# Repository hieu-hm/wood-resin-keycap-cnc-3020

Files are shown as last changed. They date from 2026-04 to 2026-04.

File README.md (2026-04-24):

# Wood Resin Keycap CNC 3020

Project for a 1u Cherry MX compatible keycap with a CNC-machined wood body and a resin stem/insert.

## Files

- `models/keycap_1u_cherry_mx_wood_body.stl` - wood body model for CAM.
- `models/keycap_1u_cherry_mx_resin_insert.stl` - square resin insert/pour block with underside Cherry MX female socket.
- `models/keycap_1u_cherry_mx_wood_resin_assembly.stl` - combined preview assembly.
- `models/keycap_1u_r1_square_recess.stl` - R1-style 1u keycap with only a square bottom recess.
- `models/keycap_1u_r1_sample_exact_square_recess.stl` - edited directly from the user's sample STL, with the underside cross removed and replaced by a square recess.
- `models/keycap_1u_hollow_bottom_no_stem.stl` - clean model drawn from scratch with a fully hollow underside and no stem.
- `drawings/keycap_1u_cherry_mx_layout.svg` - 2D dimension reference.
- `drawings/keycap_1u_r1_square_recess_layout.svg` - 2D reference for the square-recess variant.
- `drawings/keycap_1u_r1_sample_exact_square_recess_bottom.png` - bottom-view render of the sample-edited variant.
- `drawings/keycap_1u_r1_sample_exact_square_recess_side.png` - side-view render of the sample-edited variant.
- `drawings/keycap_1u_hollow_bottom_no_stem_bottom.png` - bottom-view render of the clean hollow model.
- `drawings/keycap_1u_hollow_bottom_no_stem_side.png` - side-view render of the clean hollow model.
- `cam/CNC_3020_PLUS_keycap_job_sheet.md` - machining notes for CNC 3020 Plus.
- `docs/README_keycap_1u_cherry_mx_wood_resin.md` - dimensions and manufacturing notes.
- `docs/README_keycap_1u_r1_square_recess.md` - dimensions for the square-recess variant.
- `docs/README_keycap_1u_r1_sample_exact_square_recess.md` - notes for the sample-edited exact variant.
- `docs/README_keycap_1u_hollow_bottom_no_stem.md` - notes for the clean hollow-bottom keycap.
- `scripts/make_keycap_mesh.py` - regenerates the STL/SVG/docs files.
- `scripts/make_keycap_r1_square_recess.py` - generates the R1-style square-recess variant.
- `scripts/edit_sample_r1_square_recess.py` - edits the provided sample STL and replaces the underside cross with a square recess.
- `scripts/make_keycap_hollow_bottom.py` - generates the clean hollow-bottom keycap from scratch.

## Nominal Dimensions

- Bottom: 18.2 x 18.2 mm.
- Top face: 12.8 x 12.8 mm.
- Height: 9.6 mm.
- Wall thickness: 1.25 mm.
- Top thickness: 1.65 mm.
- Resin pour pocket: 7.4 x 7.4 x 5.0 mm.
- Cherry MX socket: about 4.2 x 1.32 mm slots, centered, with about 5.0 mm resin depth available.

## Suggested Workflow

1. Open `models/keycap_1u_cherry_mx_wood_body.stl` in CAM.
2. Set units to millimeters.
3. Set origin at the keycap center, with Z zero on top of stock.
4. Machine the wood body and resin pocket.
5. Seal the wood, cast resin into the 7.4 x 7.4 x 5.0 mm square pocket or install the matching resin insert.
6. Machine/test the Cherry MX socket in resin.
7. Test fit on one switch before making a full set.

## CNC 3020 Plus Notes

Start from `cam/CNC_3020_PLUS_keycap_job_sheet.md`. Choose the postprocessor for your controller:

- GRBL/Candle: GRBL post, usually `.nc`.
- Mach3: Mach3 mill post, usually `.tap` or `.nc`.
- Offline controller: check the accepted extension before posting.

Run a CAM simulation and an air-cut before cutting the real blank.

## Regenerate Files

From the project root:

```powershell
python .\scripts\make_keycap_mesh.py
```

The script writes outputs back into `models/`, `drawings/`, and `docs/`.

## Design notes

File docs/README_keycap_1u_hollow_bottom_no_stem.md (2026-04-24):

# Keycap 1u hollow bottom, no stem

Clean model drawn from scratch for CNC/mesh preview.

Geometry:
- 1u outside bottom: 18.0 x 18.0 mm
- Overall height: about 9.6 mm
- Top reference: about 13.2 x 13.2 mm
- Bottom opening: about 14.8 x 14.8 mm
- Wall/rim thickness at bottom: about 1.6 mm
- Inner wall is near-vertical so the hollow roof matches the cavity cleanly.
- Underside is fully hollow and contains no Cherry MX stem, cross, post, bridge, or internal support.

Output:
- `keycap_1u_hollow_bottom_no_stem.stl`
- `keycap_1u_hollow_bottom_no_stem_bottom.png`
- `keycap_1u_hollow_bottom_no_stem_bottom_clean.png`
- `keycap_1u_hollow_bottom_no_stem_side.png`

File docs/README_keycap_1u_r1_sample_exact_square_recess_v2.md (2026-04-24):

# Keycap 1u R1 from sample - square recess bottom

This file is edited from the user's sample STL `1x1 R1.stl`.

Change made:
- removed the central Cherry-style cross/stem region on the underside
- replaced it with a square recessed pocket

Patch parameters used:
- square half-size: 2.8 mm
- square size: 5.60 mm
- recess depth from bottom: 3.90 mm

Output files:
- `keycap_1u_r1_sample_exact_square_recess_v2.stl`
- `keycap_1u_r1_sample_exact_square_recess_v2_bottom.png`
- `keycap_1u_r1_sample_exact_square_recess_v2_bottom_clean.png`
- `keycap_1u_r1_sample_exact_square_recess_v2_side.png`

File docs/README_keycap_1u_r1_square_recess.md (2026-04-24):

# Keycap 1u R1 style - square recessed bottom

Units: millimeters.

This model is a clean remake inspired by the reference `1x1 R1.stl`, but simplified underneath:
- no Cherry MX cross
- no resin stem geometry
- underside uses only a square recessed pocket

Generated files:
- `models/keycap_1u_r1_square_recess.stl`
- `drawings/keycap_1u_r1_square_recess_layout.svg`

Nominal dimensions:
- Bottom footprint: 18.0 x 18.0 mm
- Overall height: about 9.8 mm
- Top reference area: 13.0 x 13.0 mm
- Top reference offset: +0.8 mm in Y
- Bottom square recess: 7.4 x 7.4 x 5.0 mm deep

Notes:
- Model uses standard CAD orientation with Z up.
- Body is solid except for the square bottom recess.
- Top surface has an R1-style front/back slope plus a light dish.
- If you want the bottom recess larger, deeper, or offset, edit the values in `scripts/make_keycap_r1_square_recess.py`.

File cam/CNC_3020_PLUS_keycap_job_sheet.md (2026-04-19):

# CNC 3020 Plus job sheet - 1u Cherry MX wood + resin keycap

Units: millimeters.

Use these source files:
- Wood body CAM: `keycap_1u_cherry_mx_wood_body.stl`
- Resin insert CAM/test: `keycap_1u_cherry_mx_resin_insert.stl`
- Visual assembly only: `keycap_1u_cherry_mx_wood_resin_assembly.stl`
- 2D dimension reference: `keycap_1u_cherry_mx_layout.svg`

## Machine assumptions

- Machine: CNC 3020 Plus, 3-axis router.
- Work envelope is enough for one keycap.
- Controller can run standard G-code from CAM, commonly `.nc` or `.tap`.
- Verify whether your controller is GRBL/Candle, Mach3, or offline controller before posting G-code.

Do not run unverified G-code directly. First simulate in CAM, then air-cut above the stock.

## Suggested stock

For one keycap:
- Wood blank: 25 x 25 x 13 mm minimum.
- Safer blank: 30 x 30 x 15 mm.
- Final keycap body: about 18.2 x 18.2 x 9.6 mm.

Clamp the blank on a spoilboard. Leave at least 3 mm margin around the keycap for tabs or double-sided tape.

## Work coordinate setup

Recommended origin:
- X0/Y0: center of keycap.
- Z0: top of stock.

This matches the generated STL centerline and makes flipping/indexing easier.

## Tooling

For wood body:
- Roughing: 2.0 mm flat end mill.
- Finishing outer/top surface: 1.0 mm ball nose or 1.0 mm flat end mill.
- Inner cavity/pocket cleanup: 1.0 mm flat end mill.

For Cherry MX resin socket:
- Best: 0.8 mm to 1.0 mm flat end mill.
- Socket slot nominal is about 1.32 mm wide, so a 1.0 mm tool leaves room for finishing.

## Conservative starting feeds for small 3020 router

These are starting points only; reduce them if the spindle, frame, or bit chatters.

Wood with 1-2 mm carbide end mill:
- Spindle: 12000-18000 RPM.
- Feed: 250-600 mm/min.
- Plunge: 80-150 mm/min.
- Stepdown: 0.3-0.8 mm.
- Stepover roughing: 35-45%.
- Stepover finishing: 8-12%.

Resin with 0.8-1.0 mm end mill:
- Spindle: 10000-16000 RPM.
- Feed: 150-400 mm/min.
- Plunge: 50-100 mm/min.
- Stepdown: 0.2-0.4 mm.

## CAM operation order

### Wood body

1. Face stock lightly if needed.
2. 3D rough the outside body from `keycap_1u_cherry_mx_wood_body.stl`.
3. 3D finish the top surface.
4. Machine the underside cavity and resin pocket.
5. Machine the square resin pour pocket to about 7.4 x 7.4 x 5.0 mm.
6. Leave 0.15-0.30 mm clearance for the resin insert/pour because wood and resin dimensions move.
7. Cut the outer profile last, with tabs if not using strong double-sided tape.

### Resin stem/insert

Two practical options:

Option A - cast resin into the wood pocket:
- Seal the wood first.
- Cast resin into the 7.4 x 7.4 x 5.0 mm square pocket.
- After curing, re-zero on the underside center and machine the Cherry MX female socket.

Option B - machine/print separate insert:
- CAM from `keycap_1u_cherry_mx_resin_insert.stl`.
- Test fit in the wood pocket.
- Bond with epoxy or thin CA after checking switch fit.

## Cherry MX fit check

Before making a full set, cut only the resin socket test:
- Slot pair: about 4.2 x 1.32 mm, centered.
- Available resin depth: about 5.0 mm.
- If switch is too tight, increase slot width by 0.05 mm.
- If switch is loose, reduce slot width or use a tougher resin/epoxy mix.

## Postprocessor

Choose the postprocessor that matches your controller:
- GRBL/Candle: use a GRBL post and output `.nc`.
- Mach3: use a Mach3 mill post and output `.tap` or `.nc`.
- Offline 3020 controller: check whether it expects `.nc`, `.tap`, or `.txt`.

Minimum G-code features to confirm:
- Uses millimeters: `G21`.
- Absolute coordinates: `G90`.
- Safe retracts clear your clamps.
- Spindle command matches your controller: commonly `M3 S...`.
- Program end is accepted: commonly `M5` then `M30`.

## Safety checklist

- Simulate in CAM.
- Run an air-cut 5-10 mm above stock.
- Keep one hand near emergency stop.
- Confirm tool diameter in CAM matches the real bit.
- Confirm Z zero before every operation.
- Confirm the tool does not collide with clamps.
- Make one sacrificial test in cheap wood before using final wood/resin.

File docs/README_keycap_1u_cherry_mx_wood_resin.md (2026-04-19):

# Keycap 1u Cherry MX - wood body + resin stem insert

Units: millimeters.

Generated files:
- `keycap_1u_cherry_mx_wood_body.stl`: wooden outer keycap shell.
- `keycap_1u_cherry_mx_resin_insert.stl`: square resin insert/pour block with underside Cherry MX female socket.
- `keycap_1u_cherry_mx_wood_resin_assembly.stl`: combined preview assembly.
- `keycap_1u_cherry_mx_layout.svg`: 2D dimension reference for bottom/top/pocket/stem.

Nominal dimensions:
- 1u outside bottom: 18.2 x 18.2 mm.
- Top face: 12.8 x 12.8 mm.
- Height: 9.6 mm.
- Wall thickness: 1.25 mm.
- Top thickness: 1.65 mm.
- Resin pour pocket: 7.4 x 7.4 x 5.0 mm under the top.
- Cherry MX female socket: centered, about 4.2 x 1.32 mm each slot, depth about 5.0 mm available in resin.

Manufacturing notes:
- This is a practical starting model, not an official Cherry MX mechanical drawing.
- For CNC wood, leave 0.15-0.30 mm extra clearance around the resin insert depending on wood movement and resin shrinkage.
- Do a fit test before making a full set. Cherry-compatible switches and printers/CNC postprocessors vary.
- For resin casting, machine/print the wood body first, seal the wood, cast resin into the 7.4 x 7.4 x 5.0 mm square pocket, then finish-machine the Cherry MX socket in the resin if your casting process cannot hold that detail.
- For a production STEP file, remodel this parametric design in Fusion 360/SolidWorks/FreeCAD from the dimensions above and then toolpath from STEP.

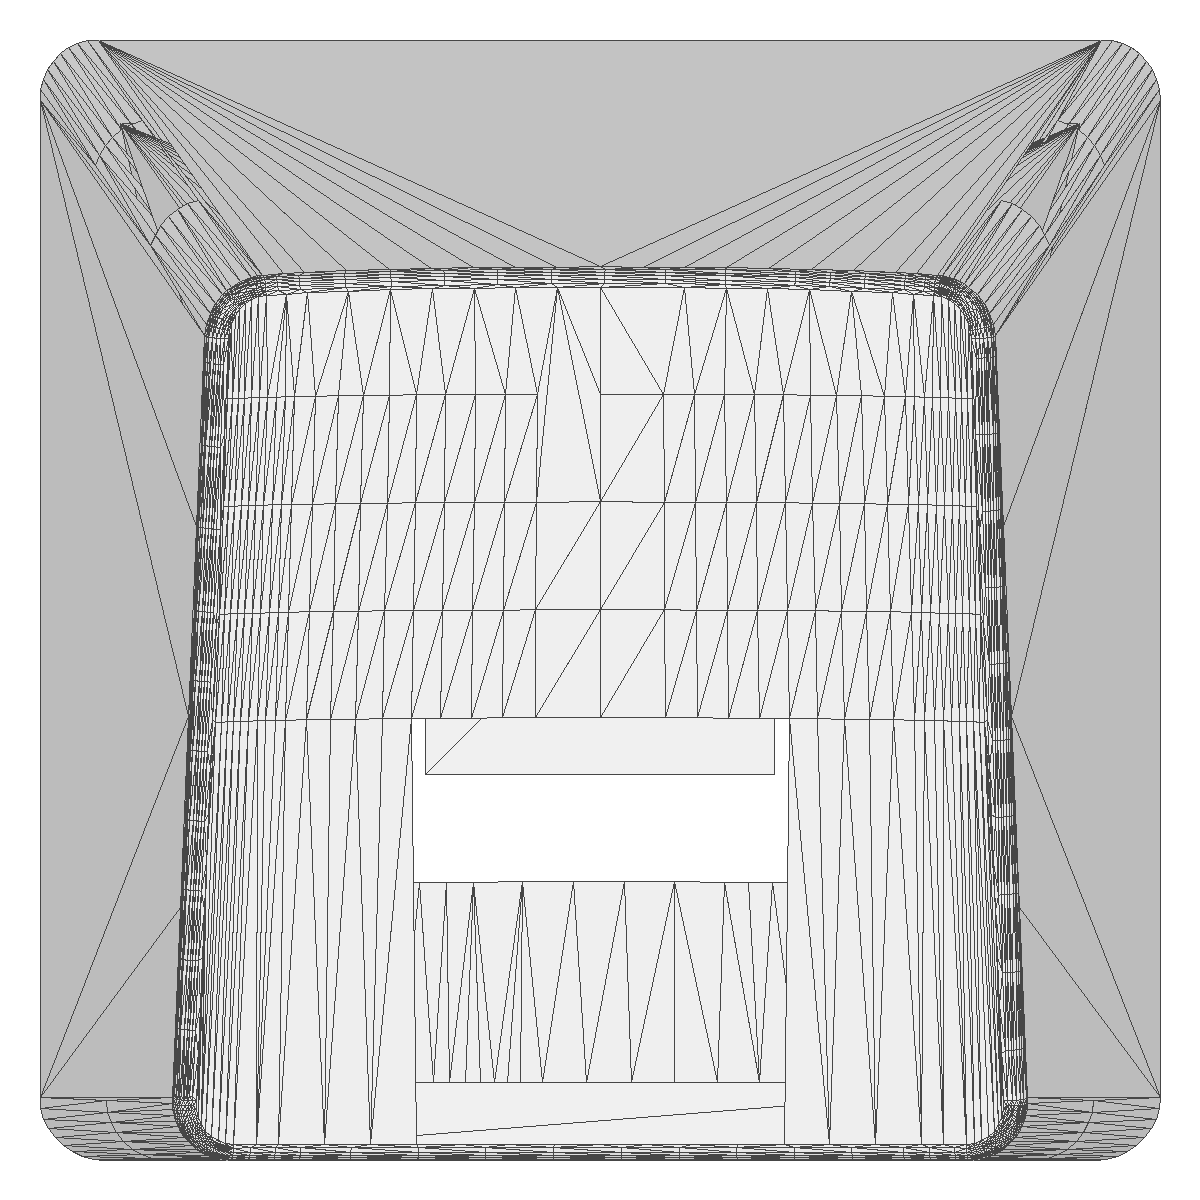
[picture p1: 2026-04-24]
drawings/keycap_1u_r1_sample_exact_square_recess_v2_bottom.png

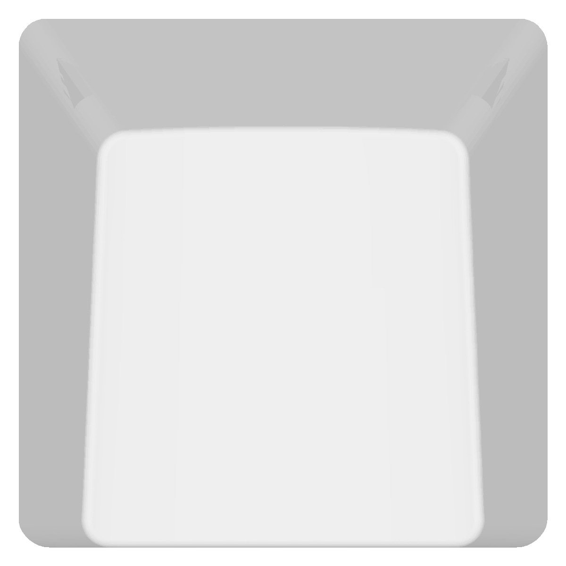
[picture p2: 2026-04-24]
drawings/keycap_1u_r1_sample_exact_square_recess_bottom_clean.png

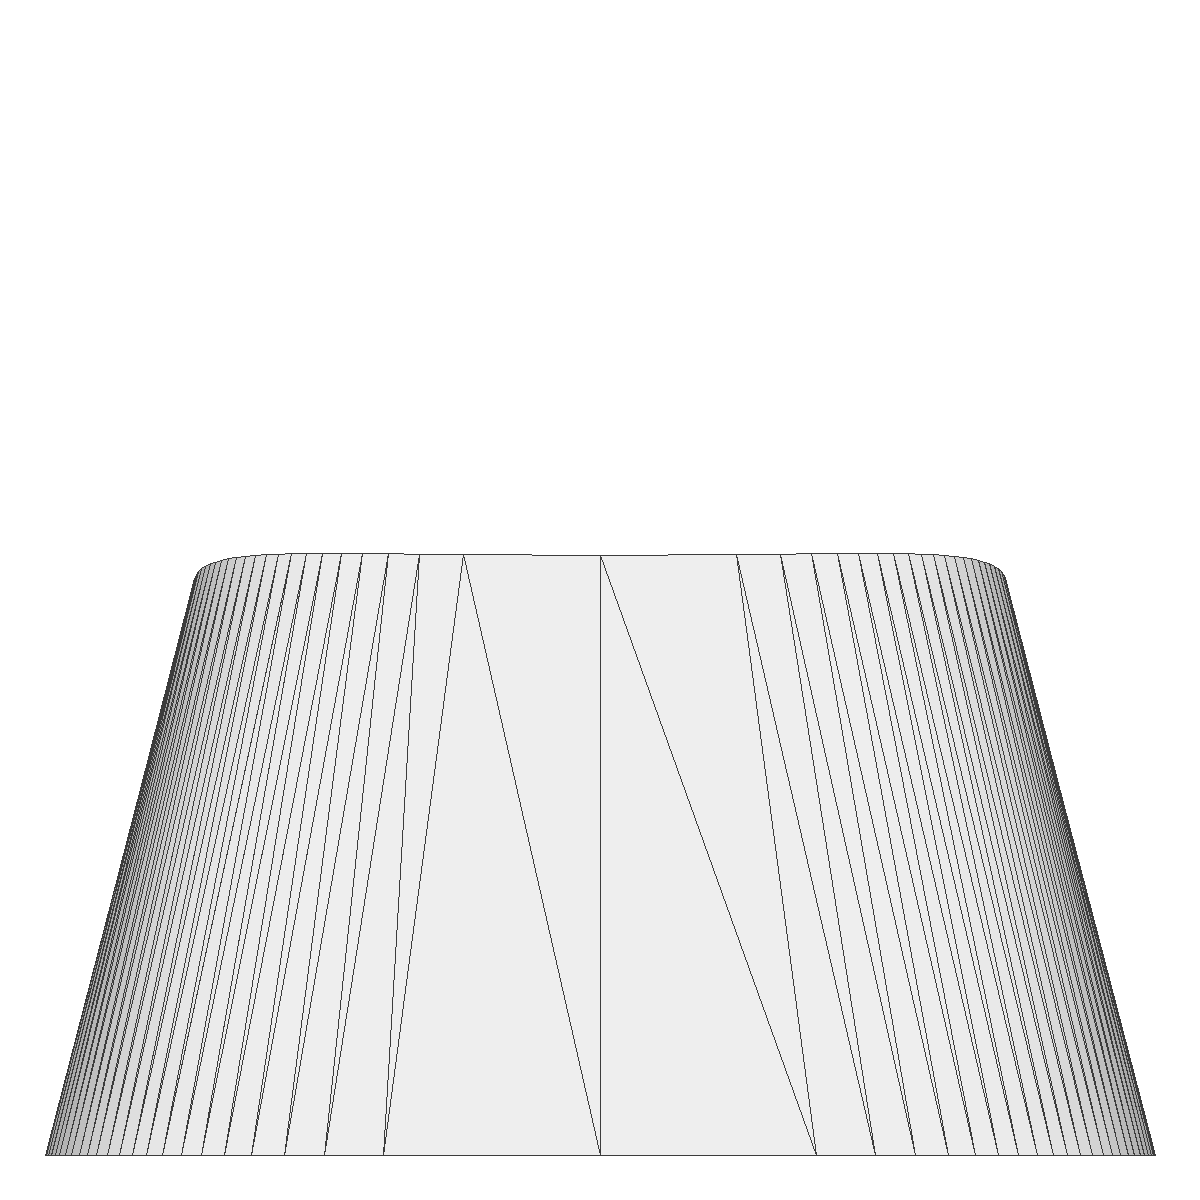
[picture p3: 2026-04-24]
drawings/keycap_1u_hollow_bottom_no_stem_flush_side.png

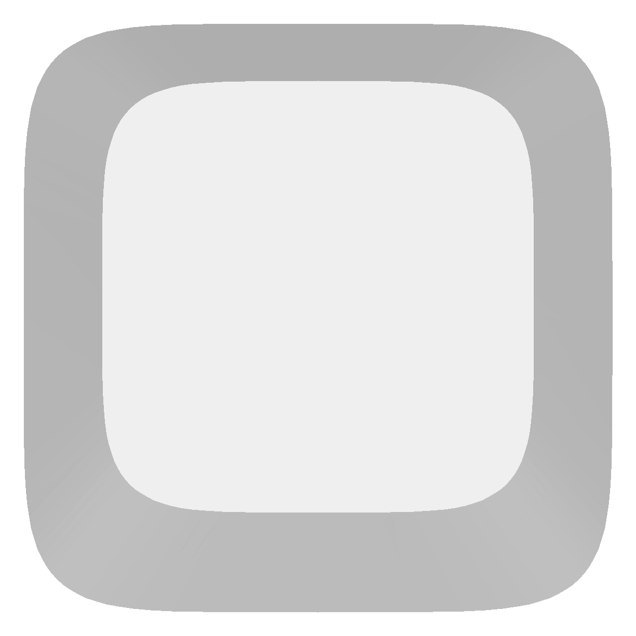
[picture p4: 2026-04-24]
drawings/keycap_1u_hollow_bottom_no_stem_bottom_clean.png

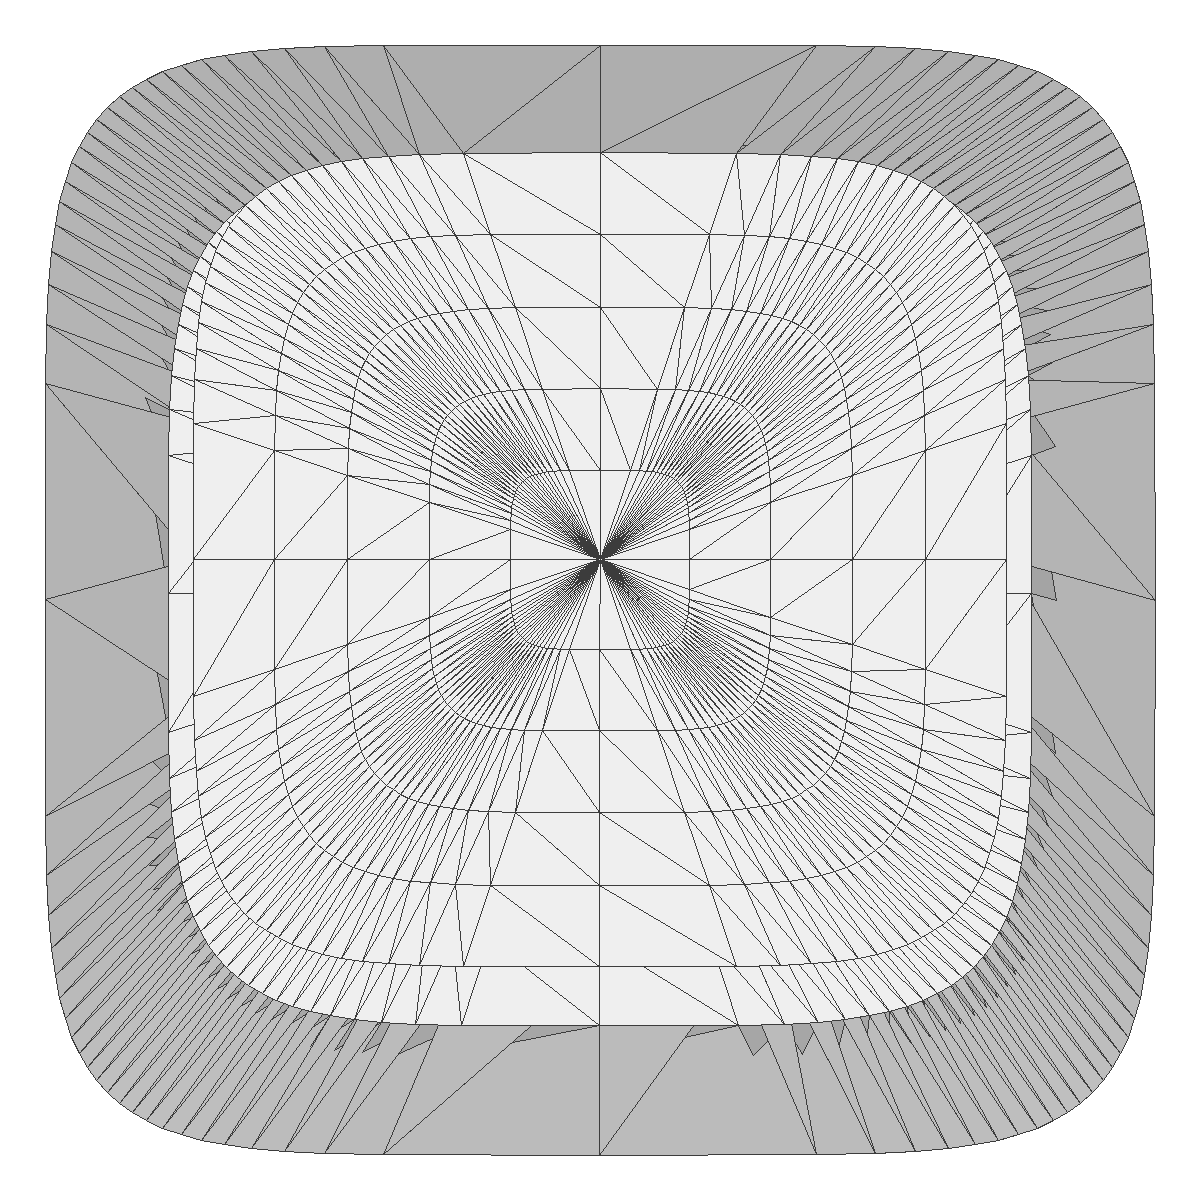
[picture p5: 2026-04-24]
drawings/keycap_1u_hollow_bottom_no_stem_bottom.png

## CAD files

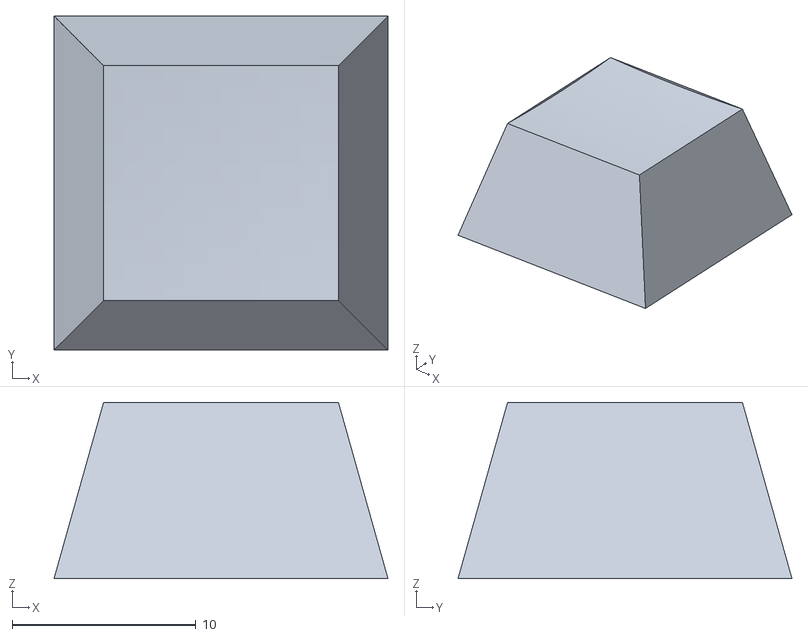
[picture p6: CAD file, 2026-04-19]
models/keycap_1u_cherry_mx_wood_resin_assembly.stl
18.2 x 18.2 x 9.60

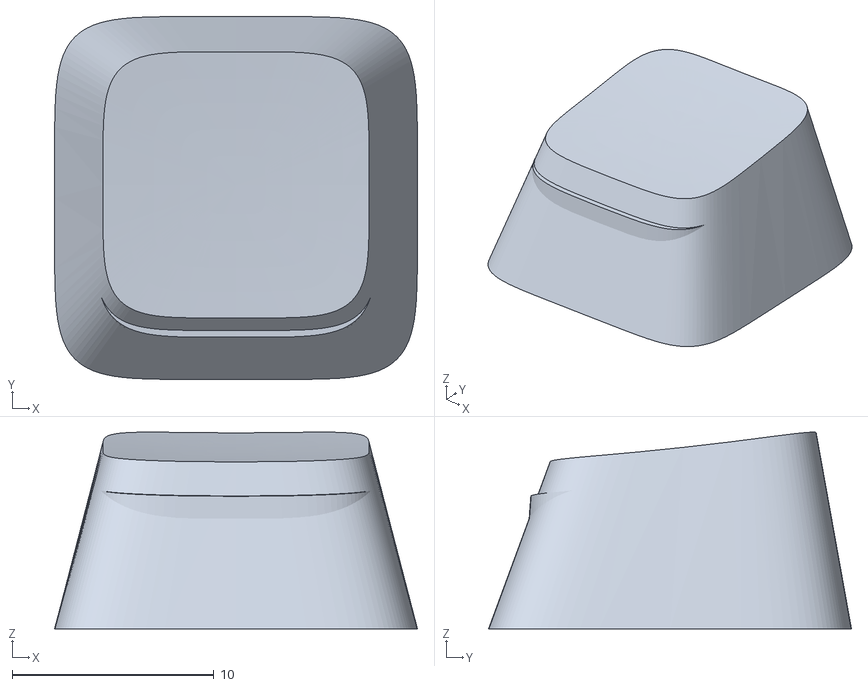
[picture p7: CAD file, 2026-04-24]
models/keycap_1u_hollow_bottom_no_stem_flush.stl
18.0 x 18.0 x 9.76

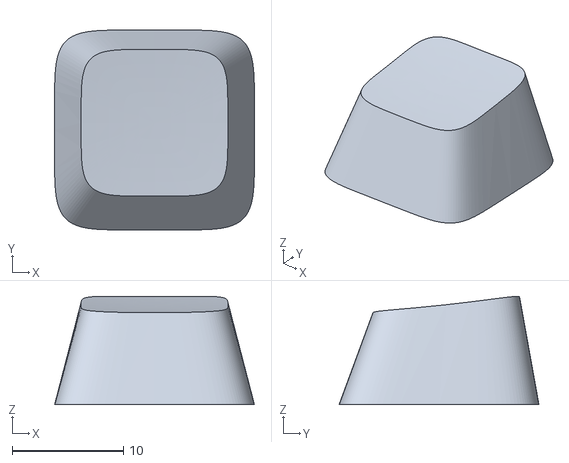
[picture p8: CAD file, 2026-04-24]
models/keycap_1u_hollow_bottom_no_stem.stl
18.0 x 18.0 x 9.76

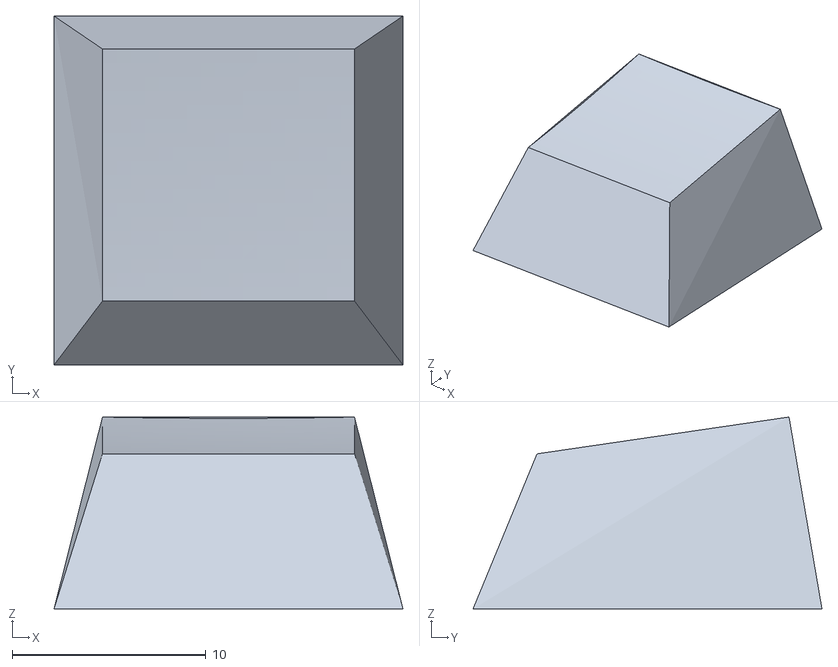
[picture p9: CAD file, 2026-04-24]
models/keycap_1u_r1_square_recess.stl
18.0 x 18.0 x 9.90

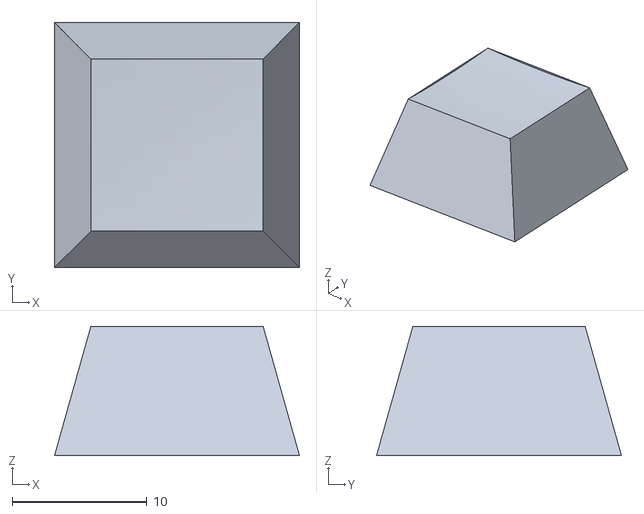
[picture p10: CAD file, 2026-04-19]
models/keycap_1u_cherry_mx_wood_body.stl
18.2 x 18.2 x 9.60

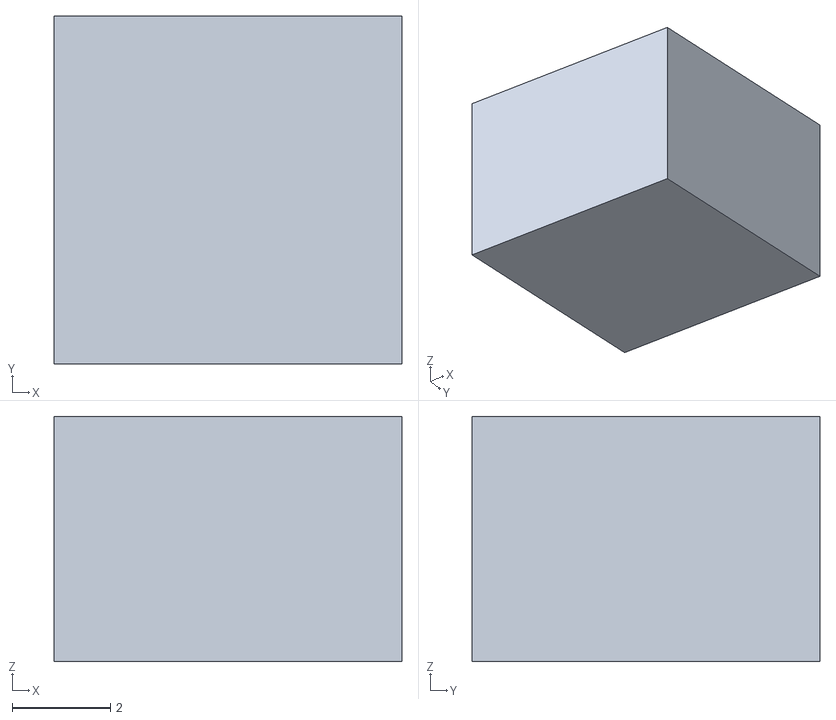
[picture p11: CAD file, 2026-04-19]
models/keycap_1u_cherry_mx_resin_insert.stl
7.10 x 7.10 x 5.00

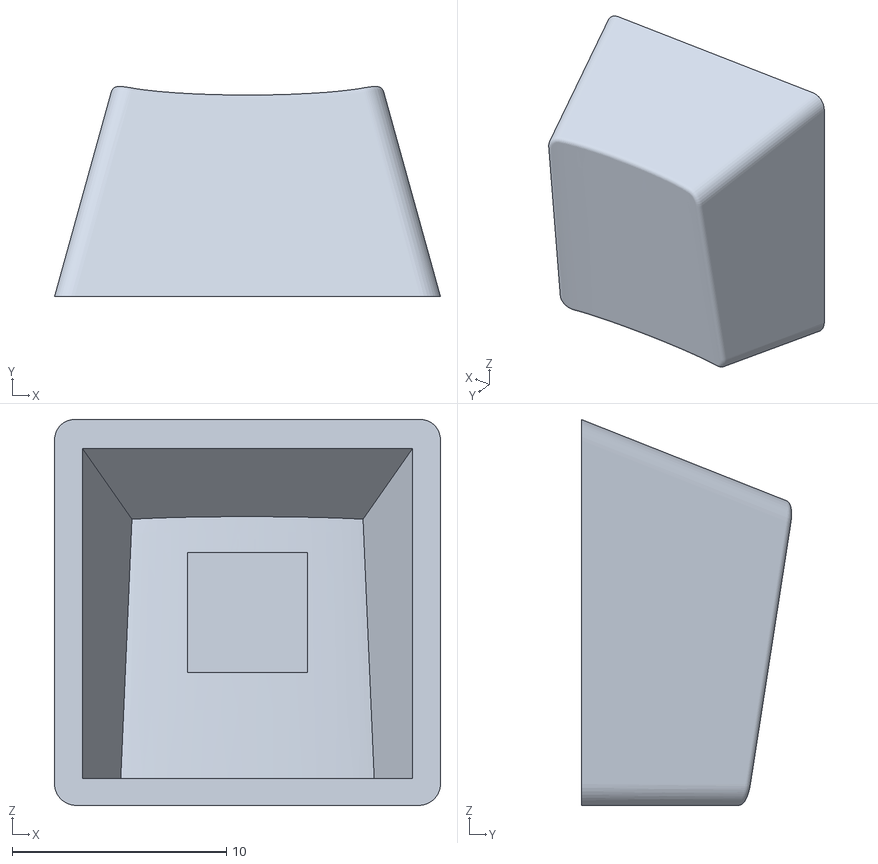
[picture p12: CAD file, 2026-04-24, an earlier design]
models/keycap_1u_r1_sample_exact_square_recess.stl
18.0 x 9.80 x 18.0

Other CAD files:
models/keycap_1u_r1_sample_exact_square_recess_v2.stl

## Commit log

2026-04-19 Add wood-resin Cherry MX keycap assets
    Add complete project assets for a 1u Cherry MX compatible keycap with a CNC-machined wood body and resin stem: top-level README, CAM job sheet (CNC_3020_PLUS), manufacturing docs, 2D layout SVG, STL 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
    [keycap_1u_cherry_mx_resin_insert.stl, keycap_1u_cherry_mx_wood_body.stl, keycap_1u_cherry_mx_wood_resin_assembly.stl]
2026-04-19 Increase resin pocket depth to 5.0 mm
    Update docs, CAM notes, drawing and models to change the resin pour pocket to a 7.4 x 7.4 x 5.0 mm square pocket and provide ~5.0 mm resin depth for the Cherry MX socket. Files updated: README.md, do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
    [keycap_1u_cherry_mx_resin_insert.stl, keycap_1u_cherry_mx_wood_body.stl, keycap_1u_cherry_mx_wood_resin_assembly.stl]
2026-04-24 Add R1-style 1u keycap (square recess)
    Introduce a new R1-style 1u keycap variant with a simple square bottom recess. Adds model, drawing, docs, and a generator script: models/keycap_1u_r1_square_recess.stl, drawings/keycap_1u_r1_square_r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
    [keycap_1u_r1_square_recess.stl]
2026-04-24 Add sample R1 square-recess variant and script
    Introduce a sample-edited R1 1u keycap variant generated from the user's STL: adds models/keycap_1u_r1_sample_exact_square_recess.stl, bottom/side render PNGs, and docs/README_keycap_1u_r1_sample_exact_square_recess.md. Adds scripts/edit_sample_r1_square_recess.py which removes the underside Cherry-style cross and replaces it with a square recessed pocket (square half-size 2.80 mm, full size 5.60 mm, recess top at 3.90 mm). Update README.md to list the new files and script.
    [keycap_1u_r1_sample_exact_square_recess.stl]
2026-04-24 Add clean bottom image and improve trimming
    Add a clean bottom rendering and tighten removal of internal geometry for the square recess. Changes: add drawings/keycap_1u_r1_sample_exact_square_recess_bottom_clean.png and reference it in the README; update models STL (regenerated) and modify scripts/edit_sample_r1_square_recess.py to: introduce OUT_BOTTOM_CLEAN, replace centroid-only tri filtering with bounding-box checks to more aggressively remove triangles inside the cavity, add an outline flag to render_projection, and produce a bottom image without polygon outlines. This prevents leftover internal geometry from appearing in the bottom view and provides a cleaner illustration.
    [keycap_1u_r1_sample_exact_square_recess.stl]
